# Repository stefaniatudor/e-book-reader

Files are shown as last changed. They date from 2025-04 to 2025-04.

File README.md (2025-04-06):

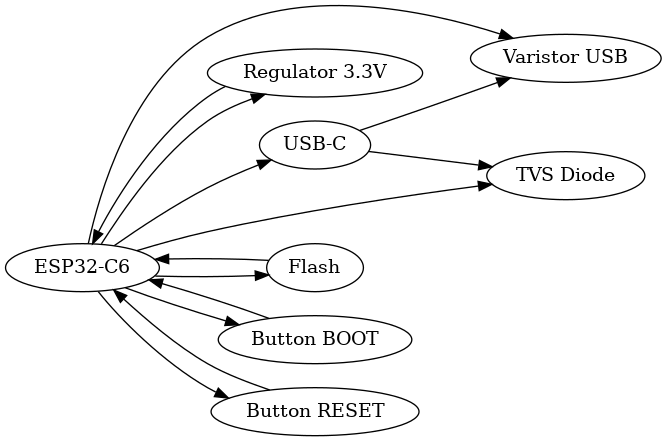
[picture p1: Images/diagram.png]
Diagrama openbook


## Functionalitate Hardware

ESP32-C6 este procesorul principal si se ocupa de comunicatie si control. Are Wi-Fi 6 si Bluetooth Low Energy integrate. Toate componentele externe sunt conectate prin magistrale digitale standard pentru a fi usor de extins sau modificat.

- **E-paper Display (SPI):** Ecran cu consum foarte mic, ideal pentru afisarea textului static. Nu consuma curent intre actualizari.
- **BME680 (I2C):** Senzor care masoara temperatura, umiditate, presiune si calitatea aerului.
- **DS3231SN (I2C):** Ceas in timp real (RTC) cu baterie de rezerva. Pastreaza ora corecta chiar si cand dispozitivul este oprit.
- **W25Q512JVEIQ (SPI):** Memorie externa de 64MB pentru stocarea cartilor si a setarilor. Viteza mare de scriere/citire.
- **MAX17048 (I2C):** Monitor de baterie care estimeaza nivelul de incarcare in timp real.
- **Conector QWIIC + Header GPIO:** Permite conectarea de module suplimentare, cum ar fi senzori, ecrane, etc.

## Alimentare si Management Energie

- **Baterie principala:** 3.7V Li-Po, folosita pentru alimentarea intregului dispozitiv.
- **Convertor de tensiune (LDO):** Combinatie intre DMG2305UX (MOSFET pentru control) si XC6220A331MR-G (LDO) – converteste tensiunea bateriei la 3.3V cu un curent maxim de 300 mA.
- **Incarcare baterie:** Se face prin USB-C, folosind circuitul dedicat MCP73831, un incarcator liniar pentru baterii Li-Po.
- **Monitorizare baterie:** Circuitul MAX17048 estimeaza cu precizie nivelul de incarcare al bateriei si trimite informatia catre ESP32-C6 prin I2C.
- **Protectie la descarcari electrostatice (ESD):**
  - La intrarea USB-C este folosit un varistor si o dioda USBLC6-2SC6Y pentru protectie.
  - Liniile SPI (folosite pentru ecran si memorie flash) sunt protejate cu componente dedicate ESD, pentru siguranta la conectarea externa sau descarcari accidentale.

## Conexiuni ESP32-C6

| Functionalitate | Pin ESP32-C6 | Descriere |
|---|---|---|
| UART pentru debug | TX / RX | Conectat la USB-C pentru programare si comunicatie seriala cu PC-ul |
| I2C | IO4 (SCL), IO5 (SDA) | Folosit pentru BME680, DS3231 si conectorul Qwiic |
| SPI | IO10 (CLK), IO11 (MOSI), IO12 (MISO), IO13 (CS) | Comunica cu memoria flash si ecranul e-paper |
| Buton BOOT | IO9 | Buton conectat la linia de BOOT pentru programare |
| LED Status | IO6 | LED utilizat pentru semnalizare vizuala (pornit, incarcare, standby etc.)|
| GPIO-uri libere | IO0, IO1, IO2, IO3 | Disponibile pentru extensii viitoare |

## Bill of Materials (BOM)

- **BME680**  
  - Link: https://www.snapeda.com/parts/BME680/Bosch/view-part/?welcome=home  
  - Datasheet: https://www.snapeda.com/parts/BME680/Bosch%20Sensortec/datasheet/

- **DMG2305UX-7**  
  - Link: https://componentsearchengine.com/part-view/DMG2305UX-7/Diodes%20Incorporated  
  - Datasheet: https://www.diodes.com//assets/Datasheets/DMG2305UX.pdf

- **W25Q512JVEIQ**  
  - Link: https://www.snapeda.com/parts/W25Q512JVEIQ/Winbond+Electronics/view-part/?ref=eda  
  - Datasheet: https://www.snapeda.com/parts/W25Q512JVEIQ/Winbond%20Electronics/datasheet/

- **MAX17048G+T10**  
  - Link: https://www.snapeda.com/parts/MAX17048G+T10/Analog+Devices/view-part/?ref=eda  
  - Datasheet: https://www.snapeda.com/parts/MAX17048G+T10/Analog%20Devices/datasheet/

- **DS3231SN**  
  - Link: https://www.snapeda.com/parts/DS3231SN%23/Analog+Devices/view-part/?ref=eda  
  - Datasheet: https://www.snapeda.com/parts/DS3231SN%23/Analog%20Devices/datasheet/

- **MCP73831**  
  - Link: https://www.digikey.com/en/models/1874108  
  - Datasheet: —

- **XC6220A331MR-G**  
  - Link: https://componentsearchengine.com/part-view/XC6220A331MR-G/Torex  
  - Datasheet: https://product.torexsemi.com/system/files/series/xc6220.pdf

- **USBLC6-2SC6Y**  
  - Link: https://www.snapeda.com/parts/USBLC6-2SC6Y/STMicroelectronics/view-part/?ref=eda  
  - Datasheet: https://www.snapeda.com/parts/USBLC6-2SC6Y/STMicroelectronics/datasheet/

- **QWIIC PRT-14417**  
  - Link: https://www.snapeda.com/parts/PRT-14417/SparkFun/view-part/  
  - Datasheet: https://www.snapeda.com/parts/PRT-14417/SparkFun%20Electronics/datasheet/

- **ESP32-C6-WROOM-1-N8**  
  - Link: https://www.snapeda.com/parts/ESP32-C6-WROOM-1-N8/Espressif+Systems/view-part/?ref=eda  
  - Datasheet: https://www.snapeda.com/parts/ESP32-C6-WROOM-1-N8/Espressif%20Systems/datasheet/

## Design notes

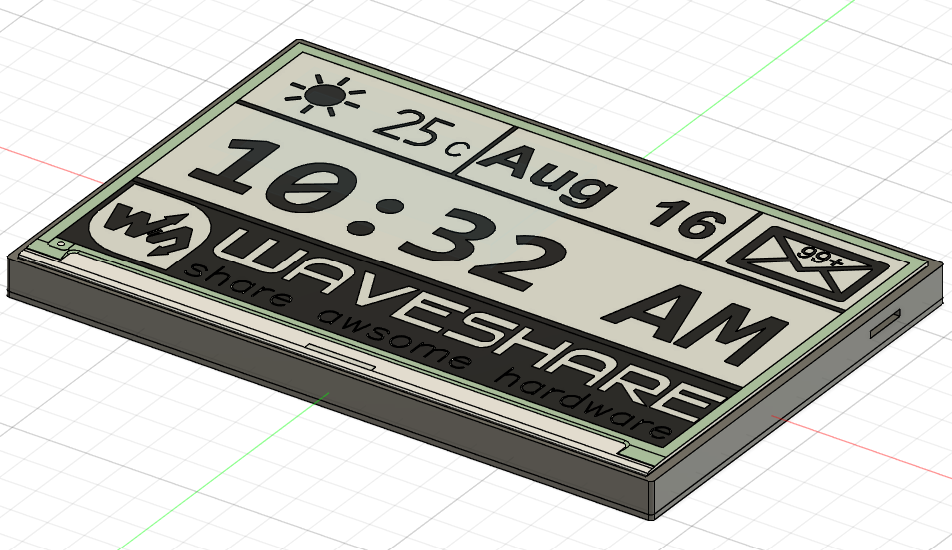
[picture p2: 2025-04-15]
Images/openbook.png

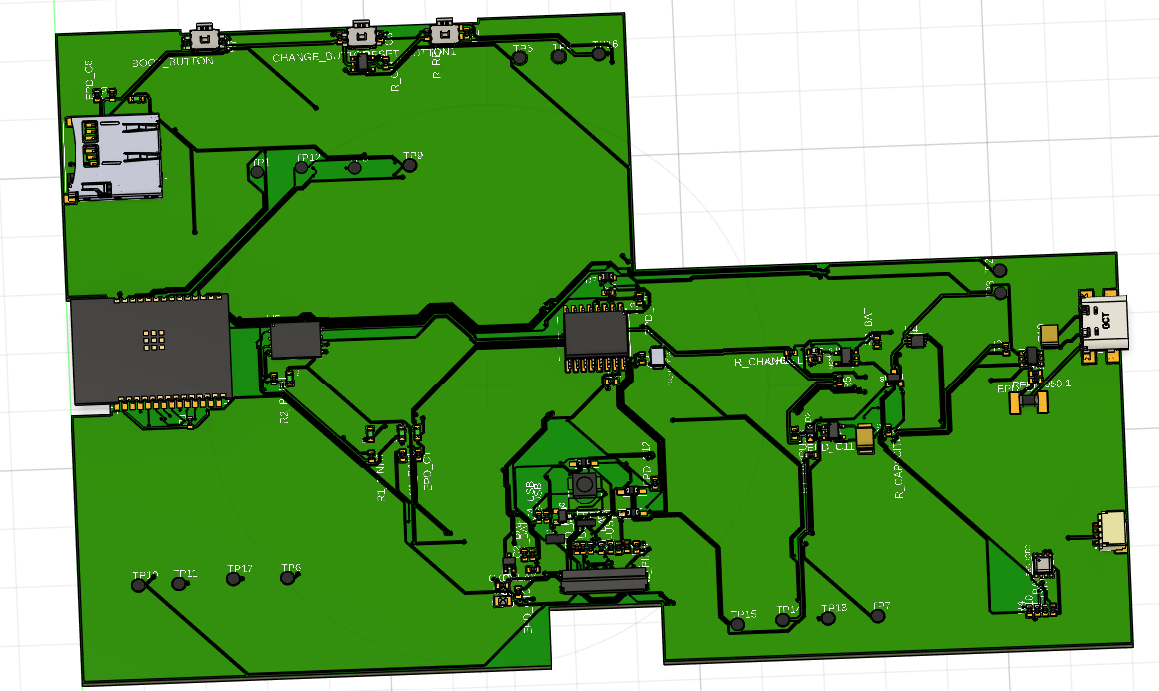
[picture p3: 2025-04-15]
Images/pcb_v2.png

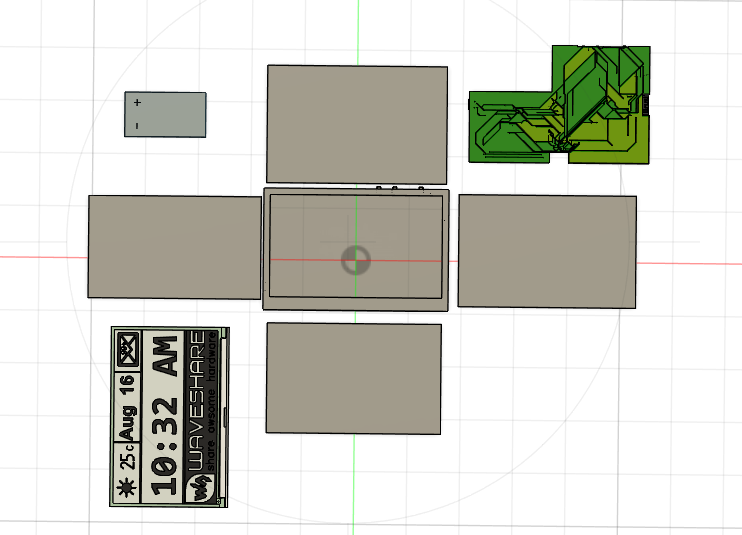
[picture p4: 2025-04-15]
Images/exploded_v2.png

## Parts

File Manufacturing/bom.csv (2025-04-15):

Qty | Value | Device | Package | Parts | Description | ARROW_PART_NUMBER | ARROW_PRICE-STOCK | AVAILABILITY | CENTROID_NOT_SPECIFIED | CHECK_PRICES | COPYRIGHT | DATASHEET | DESCRIPTION | DIGIKEY_DESCRIPTION | DIGIKEY_PART_NUMBER | HEIGHT | LEAD_FREE | MANUFACTURER_NAME | MANUFACTURER_PART_NUMBER | MF | MFR_NAME | MOUSER_PART_NUMBER | MOUSER_PRICE-STOCK | MOUSER_TESTING_PART_NUMBER | MOUSER_TESTING_PRICE-STOCK | MP | MPN | PACKAGE | POPULARITY | PREFIX | PRICE | PROD_ID | PURCHASE-URL | ROHS | SNAPEDA_LINK | SPICEMODEL | SPICEPREFIX | TEMPERATURE_RANGE_HIGH | TEMPERATURE_RANGE_LOW | TP_SIGNAL_NAME | VALUE
1 |  | ADAFRUIT_LEDCHIP-LED0603 | ADAFRUIT_CHIP-LED0603 | CHG_LED | LED
1 |  | SJ | SJ | SJ1 | SMD solder JUMPER |  |  |  |  |  |  |  |  |  |  |  |  |  |  |  |  |  |  |  |  |  |  |  | 3
1 | 0.47 | ESP32_WROVER_EAGLE-LTSPICE_RR0402 | ESP32_WROVER_EAGLE-LTSPICE_R0402 | R3 | RESISTOR, European symbol |  |  |  |  |  |  |  |  |  |  |  |  |  |  |  |  |  |  |  |  |  |  |  |  |  |  |  |  |  |  | NONE | R
1 | 01/Uf/50V | ESP32_WROVER_EAGLE-LTSPICE_CC0402 | ESP32_WROVER_EAGLE-LTSPICE_C0402 | EPD_C5 | CAPACITOR, European symbol |  |  |  |  |  |  |  |  |  |  |  |  |  |  |  |  |  |  |  |  |  |  |  |  |  |  |  |  |  |  | NONE | C
1 | 100k | ESP32_WROVER_EAGLE-LTSPICE_RR0402 | ESP32_WROVER_EAGLE-LTSPICE_R0402 | R1_PWRUSB | RESISTOR, European symbol |  |  |  |  |  |  |  |  |  |  |  |  |  |  |  |  |  |  |  |  |  |  |  |  |  |  |  |  |  |  | NONE | R
2 | 100nF | EAGLE-LTSPICE_CC0402 | EAGLE-LTSPICE_C0402 | C4_USB, C9 | CAPACITOR, European symbol |  |  |  |  |  |  |  |  |  |  |  |  |  |  |  |  |  |  |  |  |  |  |  |  |  |  |  |  |  |  | NONE | C
6 | 100nF | ESP32_WROVER_EAGLE-LTSPICE_CC0402 | ESP32_WROVER_EAGLE-LTSPICE_C0402 | C1, C2, C6, C8, C10, C_DELAY | CAPACITOR, European symbol |  |  |  |  |  |  |  |  |  |  |  |  |  |  |  |  |  |  |  |  |  |  |  |  |  |  |  |  |  |  | NONE | C
1 | 100uF TANT | RCL_CPOL-EUCT3528 | RCL_CT3528 | C3 | POLARIZED CAPACITOR, European symbol |  |  |  |  |  |  |  |  |  |  |  |  |  |  |  |  |  |  |  |  |  |  |  | 0 |  |  |  |  |  |  |  | C
7 | 10K | ESP32_WROVER_EAGLE-LTSPICE_RR0402 | ESP32_WROVER_EAGLE-LTSPICE_R0402 | R2_PINH, R4, RI_PINH, R_BOOT, R_CHANGE, R_CL1, R_RESET | RESISTOR, European symbol |  |  |  |  |  |  |  |  |  |  |  |  |  |  |  |  |  |  |  |  |  |  |  |  |  |  |  |  |  |  | NONE | R
9 | 10k | ESP32_WROVER_EAGLE-LTSPICE_RR0402 | ESP32_WROVER_EAGLE-LTSPICE_R0402 | R1, R1_PINH1, R2-PINH1, R5, R6, R7, R8, R9, R10 | RESISTOR, European symbol |  |  |  |  |  |  |  |  |  |  |  |  |  |  |  |  |  |  |  |  |  |  |  |  |  |  |  |  |  |  | NONE | R
1 | 10uF | ESP32_WROVER_EAGLE-LTSPICE_CC0402 | ESP32_WROVER_EAGLE-LTSPICE_C0402 | C7 | CAPACITOR, European symbol |  |  |  |  |  |  |  |  |  |  |  |  |  |  |  |  |  |  |  |  |  |  |  |  |  |  |  |  |  |  | NONE | C
1 | 112A-TAAR-R03_ATTEND | 112A-TAAR-R03_ATTEND | 112ATAARR03ATTEND | J4 | Micro SD Card Socket, Push-Push Type, Top Mount, SMT, H=1.83mm, 10u |  |  |  |  |  |  |  | Micro SD Card Socket | Push-Push Type | Top Mount | SMT | H=1.83mm | 10u |  |  | 1.9mm |  | ATTEND | 112A-TAAR-R03 ATTEND
1 | 15 | ESP32_WROVER_EAGLE-LTSPICE_RR0402 | ESP32_WROVER_EAGLE-LTSPICE_R0402 | R_CAPACITOR | RESISTOR, European symbol |  |  |  |  |  |  |  |  |  |  |  |  |  |  |  |  |  |  |  |  |  |  |  |  |  |  |  |  |  |  | NONE | R
1 | 1UF/50V | ESP32_WROVER_EAGLE-LTSPICE_CC0402 | ESP32_WROVER_EAGLE-LTSPICE_C0402 | EPD_C7 | CAPACITOR, European symbol |  |  |  |  |  |  |  |  |  |  |  |  |  |  |  |  |  |  |  |  |  |  |  |  |  |  |  |  |  |  | NONE | C
1 | 1Uf/50V | ESP32_WROVER_EAGLE-LTSPICE_CC0402 | ESP32_WROVER_EAGLE-LTSPICE_C0402 | EPD_C10 | CAPACITOR, European symbol |  |  |  |  |  |  |  |  |  |  |  |  |  |  |  |  |  |  |  |  |  |  |  |  |  |  |  |  |  |  | NONE | C
1 | 1uF | ESP32_WROVER_EAGLE-LTSPICE_CC0402 | ESP32_WROVER_EAGLE-LTSPICE_C0402 | C5 | CAPACITOR, European symbol |  |  |  |  |  |  |  |  |  |  |  |  |  |  |  |  |  |  |  |  |  |  |  |  |  |  |  |  |  |  | NONE | C
7 | 1uF/50V | ESP32_WROVER_EAGLE-LTSPICE_CC0402 | ESP32_WROVER_EAGLE-LTSPICE_C0402 | EPD_C1, EPD_C2, EPD_C6, EPD_C8, EPD_C9, EPD_C11, EPD_C12 | CAPACITOR, European symbol |  |  |  |  |  |  |  |  |  |  |  |  |  |  |  |  |  |  |  |  |  |  |  |  |  |  |  |  |  |  | NONE | C
1 | 2.2 | ESP32_WROVER_EAGLE-LTSPICE_RR0402 | ESP32_WROVER_EAGLE-LTSPICE_R0402 | R2 | RESISTOR, European symbol |  |  |  |  |  |  |  |  |  |  |  |  |  |  |  |  |  |  |  |  |  |  |  |  |  |  |  |  |  |  | NONE | R
1 | 200 | ESP32_WROVER_EAGLE-LTSPICE_RR0402 | ESP32_WROVER_EAGLE-LTSPICE_R0402 | R1_BAT | RESISTOR, European symbol |  |  |  |  |  |  |  |  |  |  |  |  |  |  |  |  |  |  |  |  |  |  |  |  |  |  |  |  |  |  | NONE | R
2 | 20V/4.2A/52mO/1.4W | ESP32_WROVER_SPARKFUN-DISCRETESEMI_MOSFET_PCH-DMG2305UX-7 | ESP32_WROVER_SPARKFUN-DISCRETESEMI_SOT23-3 | Q1, Q2 | P-channel MOSFETs |  |  |  |  |  |  |  |  |  |  |  |  |  |  |  |  |  |  |  |  |  |  |  |  |  |  | TRAN-14388 |  |  |  |  |  |  |  |  | 20V/4.2A/52mO/1.4W
1 | 2k | ESP32_WROVER_EAGLE-LTSPICE_RR0402 | ESP32_WROVER_EAGLE-LTSPICE_R0402 | R2_BAT | RESISTOR, European symbol |  |  |  |  |  |  |  |  |  |  |  |  |  |  |  |  |  |  |  |  |  |  |  |  |  |  |  |  |  |  | NONE | R
2 | 4.7uF | EAGLE-LTSPICE_CC0402 | EAGLE-LTSPICE_C0402 | C1_BAT1, C5_USB | CAPACITOR, European symbol |  |  |  |  |  |  |  |  |  |  |  |  |  |  |  |  |  |  |  |  |  |  |  |  |  |  |  |  |  |  | NONE | C
3 | 4.7uF | ESP32_WROVER_EAGLE-LTSPICE_CC0402 | ESP32_WROVER_EAGLE-LTSPICE_C0402 | C1_BAT, C1_BAT2, C2_BAT | CAPACITOR, European symbol |  |  |  |  |  |  |  |  |  |  |  |  |  |  |  |  |  |  |  |  |  |  |  |  |  |  |  |  |  |  | NONE | C
1 | 4.7uF/25V | ESP32_WROVER_EAGLE-LTSPICE_CC0402 | ESP32_WROVER_EAGLE-LTSPICE_C0402 | C4 | CAPACITOR, European symbol |  |  |  |  |  |  |  |  |  |  |  |  |  |  |  |  |  |  |  |  |  |  |  |  |  |  |  |  |  |  | NONE | C
2 | 5k1 | ESP32_WROVER_EAGLE-LTSPICE_RR0402 | ESP32_WROVER_EAGLE-LTSPICE_R0402 | R2-USB, R2-USB1 | RESISTOR, European symbol |  |  |  |  |  |  |  |  |  |  |  |  |  |  |  |  |  |  |  |  |  |  |  |  |  |  |  |  |  |  | NONE | R
1 | 68uH | 744043680IND_4828-WE-TPC_WRE | IND_4828-WE-TPC_WRE | L1 |  |  |  |  |  |  | Copyright (C) 2024 Ultra Librarian. All rights reserved. |  |  |  |  |  |  |  | 744043680 |  | Wurth Electronics
1 | BD5229G-TR | XC6220A331MR-G | SOT95P280X120-5N | IC1 | LDO Voltage Regulators |  |  |  |  |  |  |  | LDO Voltage Regulators |  |  | 1.2mm |  | Torex | XC6220A331MR-G |  |  | 865-XC6220A331MR-G | https://www.mouser.co.uk/ProductDetail/Torex-Semiconductor/XC6220A331MR-G?qs=AsjdqWjXhJ8ZSWznL1J0gg%3D%3D
1 | BME688 | ESP32_WROVER_BME680_BME680 | ESP32_WROVER_BME680_PSON80P300X300X100-8N | SENSOR2 | Integrated Environmental Unit |  |  | Unavailable |  |  |  |  | Integrated Environmental Unit |  |  |  |  |  |  | Bosch Sensortec |  |  |  |  |  | BME680 |  | LGA-8 Bosch Tools |  |  | None
3 | BUTTON_CUSYOMV1 | BUTTON_CUSYOMV1 | MYBUTTON | BOOT_BUTTON, CHANGE_BUTTON, RESET_BUTTON
1 | CPH3225A | CPH3225A | CAPCP3225X100N | C10_SUPERCAP | Cap 0.011F 3.3V 1210 Flat Check availability |  |  | Not in stock |  | https://www.snapeda.com/parts/CPH3225A/Seiko+Instruments/view-part/?ref=eda |  |  | 11 mF (EDLC) Supercapacitor 3.3 V 1210 (3225 Metric) - - |  |  |  |  |  |  | Seiko Instruments |  |  |  |  |  | CPH3225A |  | 1210 Seiko |  |  | None |  | https://www.snapeda.com/api/url_track_click_mouser/?unipart_id=562593&manufacturer=Seiko Instruments&part_name=CPH3225A&search_term=None |  | https://www.snapeda.com/parts/CPH3225A/Seiko+Instruments/view-part/?ref=snap
1 | DS3231SN# | DS3231SN# | SOIC127P1032X265-16N | U3 | Real Time Clock Serial 16-Pin SOIC W T/R Check availability |  |  | In Stock |  | https://www.snapeda.com/parts/DS3231SN%23/Analog+Devices/view-part/?ref=eda |  |  | Extremely Accurate I²C-Integrated RTC/TCXO/Crystal |  |  |  |  |  |  | Analog Devices |  |  |  |  |  | DS3231SN# |  | SOIC-16 Maxim |  |  | None |  | https://www.snapeda.com/api/url_track_click_mouser/?unipart_id=99048&manufacturer=Analog Devices&part_name=DS3231SN#&search_term=None |  | https://www.snapeda.com/parts/DS3231SN%23/Analog+Devices/view-part/?ref=snap
1 | ESP32-C6-WROOM-1-N8 | ESP32-C6-WROOM-1-N8 | XCVR_ESP32-C6-WROOM-1-N8 | U2 | Check availability |  |  | In Stock |  | https://www.snapeda.com/parts/ESP32-C6-WROOM-1-N8/Espressif+Systems/view-part/?ref=eda |  |  | Multiprotocol Modules ESP32-C6 module | Wi-Fi 6 in 2.4 GHz band | Bluetooth 5 | Zigbee 3.0 and Thread. ESP34-WROOM Compatible - ENGINEERING SAMPLE |  |  |  |  |  |  | Espressif Systems |  |  |  |  |  | ESP32-C6-WROOM-1-N8 |  | None |  |  | None |  |  |  | https://www.snapeda.com/parts/ESP32-C6-WROOM-1-N8/Espressif+Systems/view-part/?ref=snap
1 | ESP32C6_VARISTORCN1812 | ESP32C6_VARISTORCN1812 | ESP32C6_VARISTOR_CT/CN1812 | PFMF.050.1 | VARISTOR |  |  |  |  |  |  |  |  |  |  |  |  |  |  |  |  |  |  |  |  |  |  |  | 0
2 | ESP32_WROVER_AVX---SD0805S020S1R0_AVX_SD0805S020S1R0_0_0AVX_SD0805S020S1R0_0_0 | ESP32_WROVER_AVX---SD0805S020S1R0_AVX_SD0805S020S1R0_0_0AVX_SD0805S020S1R0_0_0 | ESP32_WROVER_AVX---SD0805S020S1R0_AVX_SD0805S020S1R0_0 | D2, D7 | Schottky Barrier Rectifier Diode |  |  |  | No |  |  | http://datasheets.avx.com/schottky.pdf |  | DIODE SCHOTTKY 20V 1A 0805 | 478-7800-1-ND |  | yes |  |  | AVX |  | 581-SD0805S020S1R0 |  |  |  |  |  | 0805 (2012 metric) |  | D |  |  |  | yes |  |  |  | +125°C | -55°C
1 | ESP32_WROVER_SPARKFUN-IC-POWER_MCP73831 | ESP32_WROVER_SPARKFUN-IC-POWER_MCP73831 | ESP32_WROVER_SPARKFUN-IC-POWER_SOT23-5 | MCP73831 | MCP73831T Li-Ion, Li-Pol Controller |  |  |  |  |  |  |  |  |  |  |  |  |  |  |  |  |  |  |  |  |  |  |  |  |  |  | IC-09995
1 | FH34SRJ-24S-0.5SH_99_ | FH34SRJ-24S-0.5SH_99_ | FH34SRJ24S05SH99 | J1 | (0.50mm) Surface Mount, Right Angle |  |  |  |  |  |  |  | 24 Position FFC | FPC Connector Contacts | (0.50mm) Surface Mount | Right Angle |  |  | 1.1mm |  | Hirose | FH34SRJ-24S-0.5SH(99) |  |  | 798-FH34SRJ24S05SH99 | https://www.mouser.co.uk/ProductDetail/Hirose-Connector/FH34SRJ-24S-0.5SH99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
1 | MAX17048G+T10 | MAX17048G+T10 | SON50P200X200X80-9N | U4 | Check availability |  |  | In Stock |  | https://www.snapeda.com/parts/MAX17048G+T10/Analog+Devices/view-part/?ref=eda |  |  | 3µA 1-Cell/2-Cell Fuel Gauge with ModelGauge |  |  |  |  |  |  | Analog Devices |  |  |  |  |  | MAX17048G+T10 |  | TDFN-8 Maxim |  |  | None |  | https://www.snapeda.com/api/url_track_click_mouser/?unipart_id=329239&manufacturer=Analog Devices&part_name=MAX17048G+T10&search_term=None |  | https://www.snapeda.com/parts/MAX17048G+T10/Analog+Devices/view-part/?ref=snap
3 | MBR0530 | MBR0530 | SOD3716X135N | D3, D4, D5 | ON SEMICONDUCTOR - MBR0530 - DIODE, SCHOTTKY, 0.5A, 30V, SOD-123 |  |  | In Stock |  | https://www.snapeda.com/parts/MBR0530/Onsemi/view-part/?ref=eda |  |  | Diode Schottky 30 V 500mA Surface Mount SOD-123 |  |  |  |  |  |  | ON Semiconductor |  |  |  |  |  | MBR0530 |  | SOD-123-2 ON Semiconductor |  |  | None |  | https://www.snapeda.com/api/url_track_click_mouser/?unipart_id=179458&manufacturer=ON Semiconductor&part_name=MBR0530&search_term=None |  | https://www.snapeda.com/parts/MBR0530/Onsemi/view-part/?ref=snap
6 | PGB1010603MR | PGB1010603MR | DIOC1608X36N | D6, D8, D9, D10, D11, D12 | Check availability |  |  | In Stock |  | https://www.snapeda.com/parts/PGB1010603MR/Littelfuse/view-part/?ref=eda |  |  | 150V (Typ) Clamp - Ipp Tvs Diode Surface Mount 0603 (1608 Metric) |  |  |  |  |  |  | Littelfuse Inc. |  |  |  |  |  | PGB1010603MR |  | 0603 Littelfuse Inc. |  |  | None |  | https://www.snapeda.com/api/url_track_click_mouser/?unipart_id=5659453&manufacturer=Littelfuse Inc.&part_name=PGB1010603MR&search_term=None |  | https://www.snapeda.com/parts/PGB1010603MR/Littelfuse/view-part/?ref=snap
1 | QWIIC_RIGHT_ANGLE | QWIIC_CONNECTORJS-1MM | JST04_1MM_RA | J3 | SparkFun I2C Standard Qwiic Connector |  |  |  |  |  |  |  |  |  |  |  |  |  |  |  |  |  |  |  |  |  |  |  |  |  |  | CONN-13694 |  |  |  |  |  |  |  |  | QWIIC_RIGHT_ANGLE
1 | SAMACSYS_PARTS_USB4110-GF-A | SAMACSYS_PARTS_USB4110-GF-A | SAMACSYS_PARTS_USB4110GFA | J2 | CONN USB 2.0 TYPE-C R/A SMT |  |  |  |  |  |  |  | CONN USB 2.0 TYPE-C R/A SMT |  |  | 3.26mm |  | GCT (GLOBAL CONNECTOR TECHNOLOGY) | USB4110-GF-A |  |  | 640-USB4110-GF-A | https://www.mouser.co.uk/ProductDetail/GCT/USB4110-GF-A?qs=KUoIvG%2F9IlYiZvIXQjyJeA%3D%3D
1 | SI1308EDL-T1-GE3 | SI1308EDL-T1-GE3 | SOT65P210X110-3N | Q3 | MOSFET N-Ch 30V 1.5A TrenchFET SC70 Vishay Si1308EDL-T1-GE3 N-channel MOSFET Transistor, 1.5 A, 30 V, 3-Pin SC-70 |  |  | In Stock |  | https://www.snapeda.com/parts/SI1308EDL-T1-GE3/Vishay+Siliconix/view-part/?ref=eda |  |  | Si1308EDL-T1-GE3 N-channel MOSFET Transistor | 1.5 A | 30 V | 3-Pin SC-70 | Siliconix / Vishay SI1308EDL-T1-GE3 |  |  |  |  |  |  | Vishay Siliconix |  |  |  |  |  | SI1308EDL-T1-GE3 |  | SOT-323 Vishay Semiconductor |  |  | None |  | https://www.snapeda.com/api/url_track_click_mouser/?unipart_id=274603&manufacturer=Vishay Siliconix&part_name=SI1308EDL-T1-GE3&search_term=None |  | https://www.snapeda.com/parts/SI1308EDL-T1-GE3/Vishay+Siliconix/view-part/?ref=snap
17 | TPTP20R | TPTP20R | TP20R | TP1, TP2, TP3, TP4, TP5, TP6, TP7, TP8, TP9, TP10, TP11, TP12, TP13, TP14, TP15, TP16, TP17 | Test pad |  |  |  |  |  |  |  |  |  |  |  |  |  |  |  |  |  |  |  |  |  |  |  | 2
1 | USBLC6-2SC6Y | USBLC6-2SC6Y | SOT95P280X145-6N | D1 | Low Cap. ESD Protection Auto SOT-23-6 STMicroelectronics USBLC6-2SC6Y, Dual Uni-Directional TVS Diode Array, 6-Pin SOT-23 |  |  | In Stock |  | https://www.snapeda.com/parts/USBLC6-2SC6Y/STMicroelectronics/view-part/?ref=eda |  |  | 17V Clamp 5A (8/20µs) Ipp Tvs Diode Surface Mount SOT-23-6 |  |  |  |  |  |  | STMicroelectronics |  |  |  |  |  | USBLC6-2SC6Y |  | SOT-23-6 STMicroelectronics |  |  | None |  |  |  | https://www.snapeda.com/parts/USBLC6-2SC6Y/STMicroelectronics/view-part/?ref=snap
1 | W25Q512JVEIQ | W25Q512JVEIQ | SON127P600X800X80-9N | U1 | Check availability |  |  | In Stock |  | https://www.snapeda.com/parts/W25Q512JVEIQ/Winbond+Electronics/view-part/?ref=eda |  |  | FLASH - NOR Memory IC 512Mb (64M x 8) SPI - Quad I/O 133 MHz 8-WSON (8x6) |  |  |  |  |  |  | Winbond Electronics |  |  |  |  |  | W25Q512JVEIQ |  | Package |  |  | None |  |  |  | https://www.snapeda.com/parts/W25Q512JVEIQ/Winbond+Electronics/view-part/?ref=snap
1 | XC6220A331MR-G | XC6220A331MR-G | SOT95P280X120-5N | IC4 | LDO Voltage Regulators |  |  |  |  |  |  |  | LDO Voltage Regulators |  |  | 1.2mm |  | Torex | XC6220A331MR-G |  |  | 865-XC6220A331MR-G | https://www.mouser.co.uk/ProductDetail/Torex-Semiconductor/XC6220A331MR-G?qs=AsjdqWjXhJ8ZSWznL1J0gg%3D%3D

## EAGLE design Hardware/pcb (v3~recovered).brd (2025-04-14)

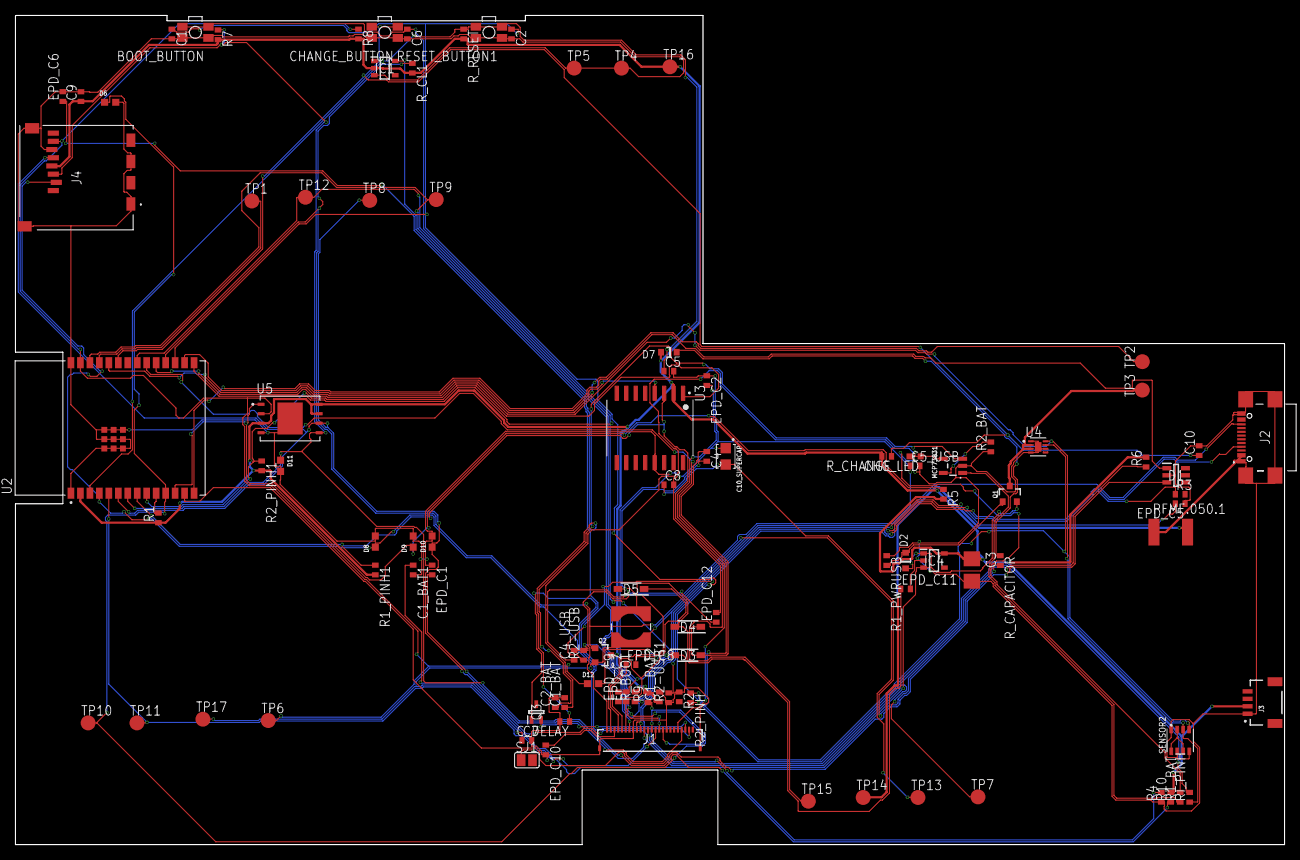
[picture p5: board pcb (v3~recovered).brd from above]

Board: 2 copper layers, 170.2 x 111.2 mm, 103 parts (0 on the bottom side), 57 nets.

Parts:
BOOT_BUTTON: MYBUTTON
C1, C2, C6, C8, C10: 100nF; ESP32_WROVER_EAGLE-LTSPICE_C0402
C1_BAT, C1_BAT2, C2_BAT: 4.7uF; ESP32_WROVER_EAGLE-LTSPICE_C0402
C1_BAT1, C5_USB: 4.7uF; EAGLE-LTSPICE_C0402
C3: 100uF TANT; RCL_CT3528
C4: 4.7uF/25V; ESP32_WROVER_EAGLE-LTSPICE_C0402
C4_USB, C9: 100nF; EAGLE-LTSPICE_C0402
C5: 1uF; ESP32_WROVER_EAGLE-LTSPICE_C0402
C7: 10uF; ESP32_WROVER_EAGLE-LTSPICE_C0402
C10_SUPERCAP: CPH3225A; CAPCP3225X100N
CHANGE_BUTTON: MYBUTTON
CHG_LED: ADAFRUIT_CHIP-LED0603
C_DELAY: 100nF; ESP32_WROVER_EAGLE-LTSPICE_C0402
D1: USBLC6-2SC6Y; SOT95P280X145-6N
D2, D7: ESP32_WROVER_AVX---SD0805S020S1R0_AVX_SD0805S020S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; ESP32_WROVER_AVX---SD0805S020S1R0_AVX_SD0805S020S1R0_0
D3, D4, D5: MBR0530; SOD3716X135N
D6, D8, D9, D10, D11, D12: PGB1010603MR; DIOC1608X36N
EPD_C1, EPD_C2, EPD_C6, EPD_C7, EPD_C8, EPD_C9, EPD_C11, EPD_C12: 1uF/50V; ESP32_WROVER_EAGLE-LTSPICE_C0402
EPD_C5: 01uf/50V; ESP32_WROVER_EAGLE-LTSPICE_C0402
EPD_C10: 1uf/50V; ESP32_WROVER_EAGLE-LTSPICE_C0402
IC1: BD5229G-TR; SOT95P280X120-5N
IC4: XC6220A331MR-G; SOT95P280X120-5N
J1: FH34SRJ-24S-0.5SH_99_; FH34SRJ24S05SH99
J2: SAMACSYS_PARTS_USB4110-GF-A; SAMACSYS_PARTS_USB4110GFA
J3: QWIIC_RIGHT_ANGLE; JST04_1MM_RA
J4: 112A-TAAR-R03_ATTEND; 112ATAARR03ATTEND
L1: 68uH; IND_4828-WE-TPC_WRE
MCP73831: ESP32_WROVER_SPARKFUN-IC-POWER_MCP73831; ESP32_WROVER_SPARKFUN-IC-POWER_SOT23-5
PFMF.050.1: ESP32C6_VARISTORCN1812; ESP32C6_VARISTOR_CT/CN1812
Q1, Q2: 20V/4.2A/52mΩ/1.4W; ESP32_WROVER_SPARKFUN-DISCRETESEMI_SOT23-3
Q3: SI1308EDL-T1-GE3; SOT65P210X110-3N
R1: 10k; ESP32_WROVER_EAGLE-LTSPICE_R0402
R1_BAT: 200; ESP32_WROVER_EAGLE-LTSPICE_R0402
R1_PINH1, R2_PINH, R2_PINH1, R4, R5, R6, R7, R8, R9, R10: 10K; ESP32_WROVER_EAGLE-LTSPICE_R0402
R1_PWRUSB: 100k; ESP32_WROVER_EAGLE-LTSPICE_R0402
R2: 2.2; ESP32_WROVER_EAGLE-LTSPICE_R0402
R2-USB, R2-USB1: 5k1; ESP32_WROVER_EAGLE-LTSPICE_R0402
R2_BAT: 2k; ESP32_WROVER_EAGLE-LTSPICE_R0402
R3: 0.47; ESP32_WROVER_EAGLE-LTSPICE_R0402
RESET_BUTTON1: MYBUTTON
RI_PINH: 10K; ESP32_WROVER_EAGLE-LTSPICE_R0402
R_BOOT: 10K; ESP32_WROVER_EAGLE-LTSPICE_R0402
R_CAPACITOR: 15; ESP32_WROVER_EAGLE-LTSPICE_R0402
R_CHANGE: 10K; ESP32_WROVER_EAGLE-LTSPICE_R0402
R_CL1: 10K; ESP32_WROVER_EAGLE-LTSPICE_R0402
R_RESET: 10K; ESP32_WROVER_EAGLE-LTSPICE_R0402
SENSOR2: BME688; ESP32_WROVER_BME680_PSON80P300X300X100-8N
SJ1: SJ
TP1, TP2, TP3, TP4, TP5, TP6, TP7, TP8, TP9, TP10, TP11, TP12, TP13, TP14, TP15, TP16, TP17: TPTP20R; TP20R
U2: ESP32-C6-WROOM-1-N8; XCVR_ESP32-C6-WROOM-1-N8
U3: DS3231SN#; SOIC127P1032X265-16N
U4: MAX17048G+T10; SON50P200X200X80-9N
U5: W25Q512JVEIQ; SON127P600X800X80-9N

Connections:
3V3: C1_BAT2.1, C3.+, C9.1, D7.2, IC1.2, IC4.5, J3.2, J4.P4, Q2.3, R1.1, R1_PINH1.2, R2_PINH1.2, R5.2, R6.2, R7.2, R8.2, R9.2, R10.2, R_BOOT.2, R_CHANGE.2, R_CL1.2, R_RESET.2, TP16.TP, U2.2, U3.2, U5.3, U5.7, U5.8
32KHZ: R2_PINH1.1, U2.9, U3.1
EPD_3V3: C7.1, EPD_C5.2, J1.15, J1.16, L1.2, Q2.2, TP17.TP
EPD_3V3_C: Q2.1, R_CL1.1, TP13.TP, U2.18
EPD_BUSY: J1.9, TP9.TP, U2.26
EPD_CS: D6.1, J1.12, R9.1, TP10.TP, U2.11
EPD_DC: J1.11, TP11.TP, U2.5
EPD_RST: J1.10, TP12.TP, U2.21
FLASH_CS: D9.1, R5.1, U2.12, U5.1
GDR: J1.2, Q3.1, R4.2
GND: BOOT_BUTTON.1, BOOT_BUTTON.2, C1.2, C1_BAT.2, C1_BAT1.2, C1_BAT2.2, C2.2, C2_BAT.2, C3.-, C4_USB.2, C5.2, C5_USB.2, C6.2, C7.2, C8.2, C9.2, C10.2, C10_SUPERCAP.1, CHANGE_BUTTON.1, CHANGE_BUTTON.2, C_DELAY.2, D1.2, D3.1, D6.2, D8.2, D9.2, D10.2, D11.2, D12.2, EPD_C1.1, EPD_C2.1, EPD_C5.1, EPD_C6.2, EPD_C7.2, EPD_C8.2, EPD_C9.2, EPD_C10.2, EPD_C11.2, EPD_C12.2, IC1.3, IC4.2, J1.8, J1.17, J1.MP1, J1.MP2, J2.A1, J2.A12, J2.B1, J2.B12, J2.MP1, J2.MP2, J2.MP3, J2.MP4, J3.1, J4.G1, J4.G2, J4.G3, J4.G4, J4.P6, MCP73831.2, R1_PWRUSB.1, R2.1, R2-USB.2, R2-USB1.1, R2_BAT.1, R4.1, RESET_BUTTON1.1, RESET_BUTTON1.2, SENSOR2.1, SENSOR2.5, SENSOR2.7, SJ1.1, TP4.TP, TP5.TP, U2.1, U2.28, U2.29_1, U2.29_2, U2.29_3, U2.29_4, U2.29_5, U2.29_6, U2.29_7, U2.29_8, U2.29_9, U3.13, U4.1, U4.4, U4.6, U4.9, U5.4, U5.9
GPIO8: R1.2, U2.10
I2C_PW: C1.1, C2.1, R2_PINH.2, RI_PINH.2, U2.17
IC2_PW: SENSOR2.2, SENSOR2.6, SENSOR2.8
INT_RTC: R1_PINH1.1, TP15.TP, U2.8, U3.3
IO/BOOT: BOOT_BUTTON.3, BOOT_BUTTON.4, C6.1, R_BOOT.1, U2.15
IO/CHANGE: C10.1, CHANGE_BUTTON.3, CHANGE_BUTTON.4, R_CHANGE.1, U2.23
MISO: D12.1, J4.P7, R8.1, TP6.TP, U2.27, U5.2
MOSI: D11.1, J1.14, J4.P3, R7.1, TP7.TP, U2.7, U5.5
unnamed: J2.B5, R2-USB.1
unnamed: J2.A5, R2-USB1.2
unnamed: C4_USB.1, C5_USB.1
unnamed: D2.2, Q1.1, R1_PWRUSB.2
unnamed: C1_BAT1.1, D2.1, IC4.1, IC4.3, Q1.2
unnamed: MCP73831.1, R1_BAT.1
unnamed: C4.2, D5.2, L1.1
unnamed: C4.1, D3.2, D4.1
unnamed: CHG_LED.C, R1_BAT.2
unnamed: C1_BAT.1, CHG_LED.A, MCP73831.4
unnamed: MCP73831.5, R2_BAT.2
unnamed: EPD_C1.2, J1.4
unnamed: EPD_C2.2, J1.5
unnamed: EPD_C6.1, J1.18
unnamed: EPD_C7.1, J1.19
unnamed: EPD_C8.1, J1.20
unnamed: EPD_C10.1, J1.22
unnamed: EPD_C12.1, J1.24
unnamed: C_DELAY.1, IC1.5
unnamed: D7.1, R_CAPACITOR.1
PREVGH: D5.1, EPD_C9.1, J1.21
PREVGL: D4.2, EPD_C11.1, J1.23
RESE: J1.3, Q3.2, R3.1
RESET: C5.1, IC1.1, RESET_BUTTON1.3, RESET_BUTTON1.4, R_RESET.1, U2.3
RTC_RST: U2.16, U3.4
RX: TP2.TP, U2.24
SCK: D10.1, J1.13, J4.P5, R6.1, TP8.TP, U2.6, U5.6
SCL: R2_PINH.1, SENSOR2.4, U2.20, U4.7
SDA: RI_PINH.1, SENSOR2.3, U2.19, U4.8
SS_SD: D8.1, J4.P2, R10.1, U2.4
TX: TP1.TP, U2.25
USB_D+: D1.1, U2.14
USB_D-: D1.3, U2.13
VBAT: Q1.3, TP3.TP, U4.2, U4.3
VBBAT: C2_BAT.1, MCP73831.3
VBUS: PFMF.050.1.2, TP14.TP
VRTC: C8.1, C10_SUPERCAP.2, R_CAPACITOR.2
VUSB: J2.A4, PFMF.050.1.1

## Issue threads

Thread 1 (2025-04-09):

Warnings si erori schematic

AndreeaViky, 2025-04-09:
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

Ai mai multe erori si warnings in schematic, care ar trebui rezolvate pentru ca iti influenteaza si PCB-ul. Din aceste warnings unele sunt pentru ca nu s-au conectat bine layerurile de net si trebuie conectate mai bine. Warningurile de POWER trebuie sa le dai approve, la fel si la "SJ1 has no value", "FRAME1 has no value", "CHG_LED has no value". Restul trebuie rezolvate si facuta rutarea iar.

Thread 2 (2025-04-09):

Via stitching

AndreeaViky, 2025-04-09:
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

La PCB, pe langa componenta U2 trebuie sa ai pus un via stitching care sa acopere si layerul de bottom si layerul de top. Via stitching-ul este bun pentru îmbunătățirea conectivitatii între straturi, reducerea interferențele electromagnetice și ajută la disiparea căldurii în placuta PCB.

Closed 2025-04-14.

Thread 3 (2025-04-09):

Trasee de putere si grosimea lor

AndreeaViky, 2025-04-09:
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
Ai trasee de putere pe buttom si ar trebui sa fie pe top.

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
Sunt mai multe trasee de putere, nu doar 4. Sunt 7 in total: VBUS, VUSB, VRTC, VBAT, EPD_3V3_C, EPD_3V3 si 3V3.

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
Grosimea firelor la firele de putere sunt bine de 0.3, dar la firele celelalte, grosimea trebuie sa fie de 0.15mm.

Closed 2025-04-14.

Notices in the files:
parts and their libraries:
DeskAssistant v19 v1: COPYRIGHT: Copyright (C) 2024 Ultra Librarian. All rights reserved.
